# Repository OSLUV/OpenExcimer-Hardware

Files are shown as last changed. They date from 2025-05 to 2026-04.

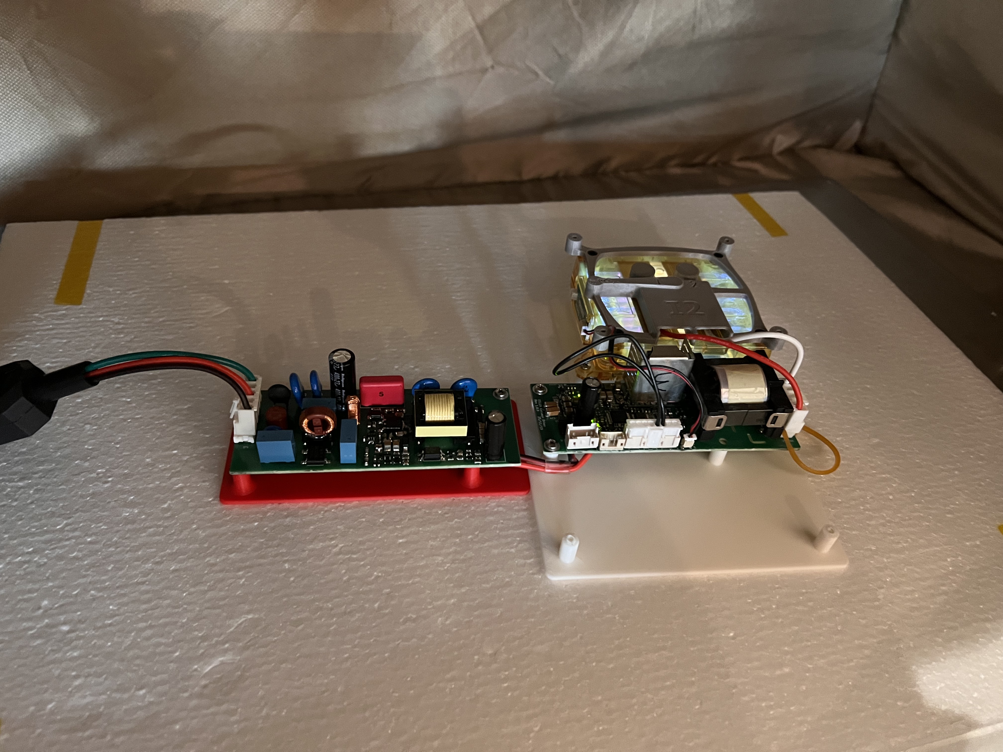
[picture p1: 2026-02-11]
Rev 1.0.0 - Open Excimer EMI Precompliance Data - 10FEB2026/OpenExcimer - Linear Arrangement - Test Set Up.jpeg

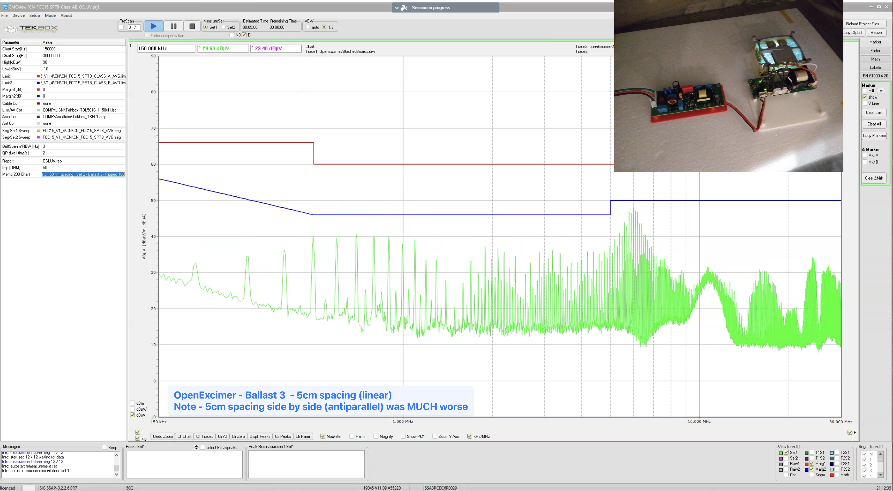
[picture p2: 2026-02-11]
Rev 1.0.0 - Open Excimer EMI Precompliance Data - 10FEB2026/Other Tests/OpenExcimer - 5cm spacing - Linear Arrangement - Passes Class B.png

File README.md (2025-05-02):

# OpenExcimer-Hardware
Hardware for OSLUV open source high voltage excimer lamp driver/ballast intended for 222nm KrCl excimer lamps

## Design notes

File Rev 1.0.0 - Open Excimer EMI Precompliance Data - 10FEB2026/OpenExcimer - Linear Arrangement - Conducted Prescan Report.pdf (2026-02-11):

## EMCview Pre-Compliance Measurement Report 2/10/2026 5:30:08 PM

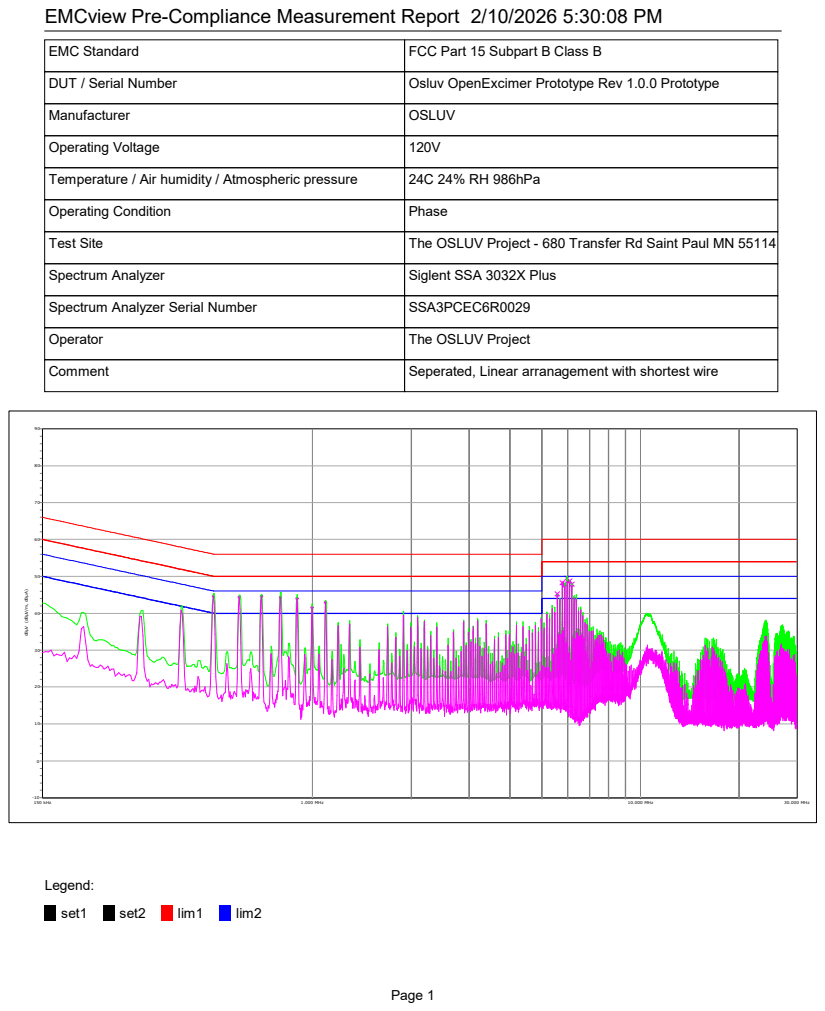
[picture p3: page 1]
EMC Standard; FCC Part 15 Subpart B Class B; DUT / Serial Number; Osluv OpenExcimer Prototype Rev 1.0.0 Prototype; Manufacturer; OSLUV; Operating Voltage; Temperature / Air humidity / Atmospheric pressure; 24C 24% RH 986hPa; Operating Condition; Phase; Test Site; The OSLUV Project - 680 Transfer Rd Saint Paul MN 55114; Spectrum Analyzer; Siglent SSA 3032X Plus; Spectrum Analyzer Serial Number; SSA3PCEC6R0029; Operator; The OSLUV Project; Comment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

EmcView: V11.09 #55220
Project:
Project: [CN_FCC15_SPTB_Class_AB_OSLUV.prj]

Set1:
SEG: FCC15_V1_4\CN\CN_FCC15_SPTB_QP.seg
SEG: FCC15_V1_4\CN\CN_FCC15_SPTB_AVG.seg_rtr10 LIM: FCC15_V1_4\CN\CN_FCC15_SPTB_CLASS_B_QP.lim

Set2:
SEG: FCC15_V1_4\CN\CN_FCC15_SPTB_AVG.seg
SEG: FCC15_V1_4\CN\CN_FCC15_SPTB_PK.seg_rtr10 LIM: FCC15_V1_4\CN\CN_FCC15_SPTB_CLASS_B_AVG.lim

HW Setup:
LISN: COMP\LISN\Tekbox_TBL5016_1_50uH.lsc CABLE:none
ANT:none
AMP:COMP\Amplifiers\Tekbox_TBFL1.amp ANT1:none

Page 2

Peaks Set1

Nb | Det | Freq | Level | Lim | Margin | *DET | *Freq | *Level | *Lim | *Margin | Result
| | [kHz] | dBµV | dBµV | [dB] | | [kHz] | dBµV | dBµV | [dB]

Peaks Set2

Nb | Det | Freq | Level | Lim | Margin | *DET | *Freq | *Level | *Lim | *Margin | Result
| | [kHz] | dBµV | dBµV | [dB] | | [kHz] | dBµV | dBµV | [dB]
1 | VAV | 49 7.8 | 44.56 | 46.03 | 1.47 | | | | | | passed
2 | VAV | 598.07 | 44.39 | 46.00 | 1.61 | | | | | | passed
3 | VAV | 698.33 | 44.58 | 46.00 | 1.42 | | | | | | passed
4 | VAV | 79 8.6 | 44.34 | 46.00 | 1.66 | | | | | | passed
5 | VAV | 895.73 | 44.03 | 46.00 | 1.97 | | | | | | passed
6 | VAV | 996 | 41.61 | 46.00 | 4.39 | | | | | | passed
7 | VAV | 1 096.27 | 42.97 | 46.00 | 3.03 | | | | | | passed
8 | VAV | 5 580 | 44.83 | 50.00 | 5.17 | QP | 5 580 | 45.24 | 60.00 | 14.76 | passed
9 | VAV | 5 780 | 48.01 | 50.00 | 1.99 | QP | 5 780 | 48.25 | 60.00 | 11.75 | passed
10 | VAV | 5 880 | 47.34 | 50.00 | 2.66 | QP | 5 880 | 47.95 | 60.00 | 12.05 | passed
11 | VAV | 5 980 | 48.64 | 50.00 | 1.36 | QP | 597 5.5 | 49.52 | 60.00 | 10.48 | passed
12 | VAV | 6 080 | 48.42 | 50.00 | 1.58 | QP | 607 5.5 | 48.74 | 60.00 | 11.26 | passed
13 | VAV | 6 176.67 | 47.45 | 50.00 | 2.55 | QP | 6 176.67 | 47.91 | 60.00 | 12.09 | passed
14 | VAV | 6 276.67 | 44.05 | 50.00 | 5.95 | | | | | | passed

Page 3

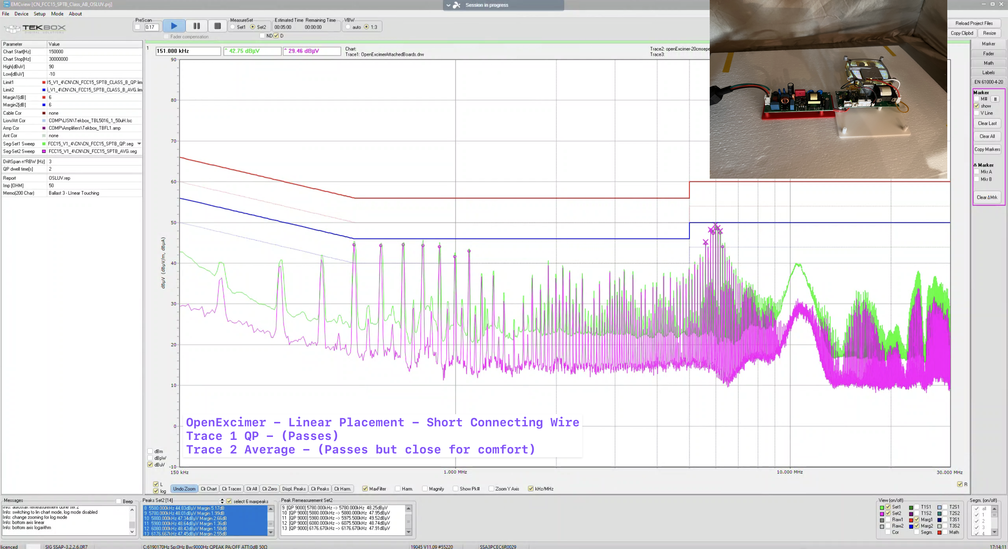
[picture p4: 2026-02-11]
Rev 1.0.0 - Open Excimer EMI Precompliance Data - 10FEB2026/OpenExcimer - Linear Arrangement - Conducted Prescan Overview.png

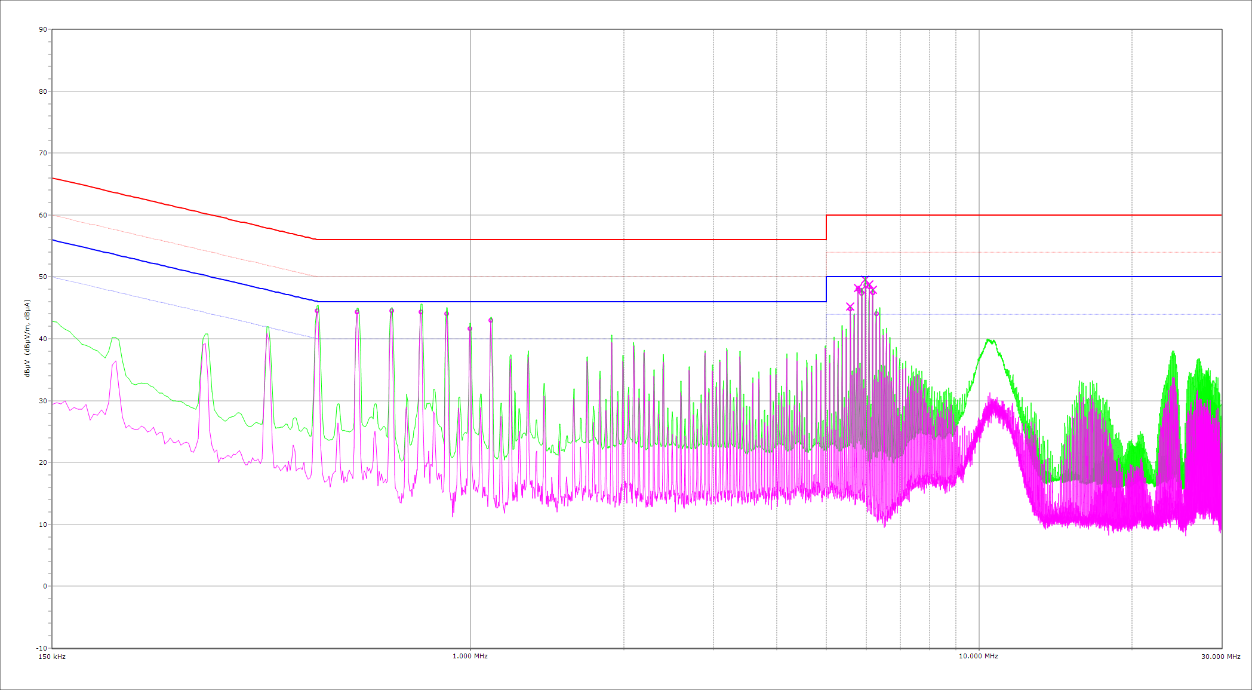
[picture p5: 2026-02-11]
Rev 1.0.0 - Open Excimer EMI Precompliance Data - 10FEB2026/OpenExcimer - Linear Arrangement - Conducted Prescan.png

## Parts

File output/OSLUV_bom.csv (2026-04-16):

Designator | Comment | Footprint | Manufacturer_Part_Number | JLCPCB Part #
L2 | 10uH | Inductor_SMD:L_0805_2012Metric | MLZ2012N100LT000 | C88182
F1 | 1A | Fuse:Fuse_1206_3216Metric | 0440001.WR | C2934573
R35 | 0R02 1% 1206 | Resistor_SMD:R_1206_3216Metric | PA1206FRF470R02L | C728292
R65,R66 | 0R22 1206 | Resistor_SMD:R_1206_3216Metric | RL1206FR-070R22L | C155692
R57 | 100k 0603 | Resistor_SMD:R_0603_1608Metric | RC0603FR-07100KL | C14675
C3,C4,C25,C27,C28,C29,C32,C33,C34,C35,C41,C44,C46,C54 | 100n 0603 | Capacitor_SMD:C_0603_1608Metric | CL10B104KC8NNNC | C15725
C40,C48,C57 | 100p 0603 | Capacitor_SMD:C_0603_1608Metric | CL10C101JC8NNNC | C296717
R29,R44,R45,R54 | 100R 0603 | Resistor_SMD:R_0603_1608Metric | RC0603FR-07100RL | C105588
R33,R34,R37,R46,R47,R52,R55,R58,R73,R74,R75,R79,R82 | 10k 0603 | Resistor_SMD:R_0603_1608Metric | RC0603FR-0710KL | C98220
R48,R78 | 10Meg 0603 | Resistor_SMD:R_0603_1608Metric | RC0603FR-0710ML | C114606
C38 | 10n 0603 | Capacitor_SMD:C_0603_1608Metric | CL10B103KC8NNNC | C84709
C49,C50 | 10p 1% 600V 1206 | Capacitor_SMD:C_1206_3216Metric | CC1206JKNPOCBN100 | C107172
R28,R30 | 10R 0603 | Resistor_SMD:R_0603_1608Metric | RC0603FR-0710RL | C109318
C5,C16,C17,C30,C31,C36,C37,C39,C43,C45,C47,C56 | 10µ X7R 1210 | Capacitor_SMD:C_1210_3225Metric | CL32B106KBJNNNE | C138687
R69 | 12k 0.1% 0603 | Resistor_SMD:R_0603_1608Metric | RT0603BRD0712KL | C326735
R60,R63 | 150R 0805 | Resistor_SMD:R_0805_2012Metric | RC0805FR-07150RL | C114523
R70,R71 | 180R 1206/MMA | Resistor_SMD:R_1206_3216Metric | MMA02040C1800FB300 | C2928662
L1,L5 | 1812_744045008 | Inductor_SMD_Wurth:L_Wurth_WE-LQ-1812 | 744045008
R64 | 18k 0603 | Resistor_SMD:R_0603_1608Metric | RC0603FR-0718KL | C114610
IC8 | 1ED44175N01BXTSA1 | Package_TO_SOT_SMD:SOT-23-6 | 1ED44175N01B | C530933
R27,R36,R38,R39,R61,R62,R77 | 1k 0603 | Resistor_SMD:R_0603_1608Metric | RC0603FR-071KL | C22548
R31,R32,R51 | 1k5 0603 | Resistor_SMD:R_0603_1608Metric | RC0603FR-071K5L | C114668
R67,R68 | 1M 1% 500V 1206 | Resistor_SMD:R_1206_3216Metric | KTR18EZPF1004 | C253347
C26,C53 | 1n 0603 | Capacitor_SMD:C_0603_1608Metric | CL10B102KC8NNNC | C153291
C51 | 1n 1% C0G 0603 | Capacitor_SMD:C_0603_1608Metric | CC0603FRNPO0BN102 | C576765
C55 | 1u 0603 | Capacitor_SMD:C_0603_1608Metric | CL10B105KB8NQNC | C5199872
C1 | 1u X7R 0805 | Capacitor_SMD:C_0805_2012Metric | CL21B105KBFNNNE | C28323
R49 | 220k 0603 | Resistor_SMD:R_0603_1608Metric | RC0603FR-07220KL | C123420
C6,C24 | 2211_8853522130151 | Capacitor_SMD_Wurth:C_Wurth_WCAP-CSSA-2211 | SCC2211X222K502TS | C2915770
R80 | 22k 0603 | Resistor_SMD:R_0603_1608Metric | RC0603FR-0722KL | C114065
R40,R41,R53 | 2k2 0603 | Resistor_SMD:R_0603_1608Metric | AC0603FR-072K2L | C125931
C101 | 330µ 35V | Capacitor_THT:CP_Radial_D8.0mm_P3.50mm | 35ZLJ330M8X20 | C88770
R76 | 33R 0603 | Resistor_SMD:R_0603_1608Metric | RC0603FR-0733RL | C108661
R50 | 39k 0603 | Resistor_SMD:R_0603_1608Metric | RC0603FR-0739KL | C163424
R56,R72 | 3k3 0603 | Resistor_SMD:R_0603_1608Metric | RC0603FR-073K3L | C108078
D10 | 3KASMC24AHE3 | Diode_SMD:D_SMC | 3KASMC24A | C1983631
L3,L4 | 4030_74438357068 | Inductor_SMD_Wurth:L_Wurth_WE-MAPI-4030 | 74438357068
C52 | 47n 0603 | Capacitor_SMD:C_0603_1608Metric | CL10B473KC8WPNC | C307354
R59 | 5k6 0603 | Resistor_SMD:R_0603_1608Metric | RC0603FR-075K6L | C114627
R42,R43 | 680R 0805 | Resistor_SMD:R_0805_2012Metric | RC0805FR-07680RL | C114549
IC5,IC6 | AP63300WU-7 | SOT95P280X90-6N | AP63300WU-7 | C2158012
J5 | B4B-PH-K-S_LF__SN_ | Hansmann_Kontakte:B4B-PH-K-S | B4B-PH-K-S(LF)(SN) | C131334
J1 | B04B-XASK-1_LF__SN_ | B04BXASK1LFSN | B04B-XASK-1(LF)(SN) | C264994
J2 | B08B-XASK-1-A_LF__SN_ | Connector_JST:JST_XA_B08B-XASK-1-A_1x08_P2.50mm_Vertical | B08B-XASK-1-A(LF)(SN) | C491710
J6 | B2P5-VH | Hansmann:CONN_B2P5-VH_JST | B2P5-VH | C594162
D16,D17,D18,D19,D20,D21 | BAT54J | Diode_SMD:D_SOD-323F | BAT54JFILM | C86299
T3 | BC817-40 | Package_TO_SOT_SMD:SOT-23 | BC817-40,215 | C52801
J4 | BM02B-SRSS-TB_LF__SN_ | Hansmann:BM02BSRSSTBLFSN | BM02B-SRSS-TB(LF)(SN) | C160388
D13,D14 | D5V0P4UR6SO-7 | SOT95P285X140-6N | D5V0P4UR6SO-7 | C531179
T2,T4,T5 | DCX114EU-7-F | SOT65P210X110-6N | DCX114EU-7-F | C460018
L101 | ETD29 | B66359B1013T001 | B66359B1013T001
T101 | IMZC120R078M2H | Package_TO_SOT_THT:TO-247-4_Vertical | IMZC120R078M2HXKSA1 | C44184296
IC4 | INA210 | Package_TO_SOT_SMD:SOT-363_SC-70-6 | INA210AIDCKR | C353893
M1 | K 274 MI 247 V | Hansmann_Kühlkörper:FK 274 MI 247 V | FK 274 MI 247 V
D12,D15 | LED gr 0603 | LED_SMD:LED_0603_1608Metric | XL-1608UGC-04 | C965804
D11 | LED rd 0603 | LED_SMD:LED_0603_1608Metric | XL-1608SURC-06 | C965799
IC2 | LM2901 | Package_SO:TSSOP-14_4.4x5mm_P0.65mm | LM2901PWR | C54868
IC7 | LP2985-33DBVR | SOT95P280X145-5N | LP2985-33DBVR | C95414
IC1 | OPA2356AIDGKR | Package_SO:VSSOP-8_3.0x3.0mm_P0.65mm | OPA2356AIDGKR | C2057371
F2 | Polyfuse 200 mA | Fuse:Fuse_1206_3216Metric | MF-NSMF020-2 | C185112
TH1 | PTC 680R 80°C | Resistor_SMD:R_0805_2012Metric | B59721A0080A062 | C2655235
M2 | Silicone gap pad, 200µm, Ubd≥5kV, λ≥1.9 W/mK. 24 x 22 mm. Acc. to drawing from 08.01.2026 | Hansmann_Kühlkörper:GapPad_19mm | KU-CG20
IC3 | STM32G071KBT6 | Hansmann:QFP80P900X900X160-32N | STM32G071KBT6 | C529348
VR1 | TC33X-2-103E | TC33X2503E | TC33X-2-103E | C719176

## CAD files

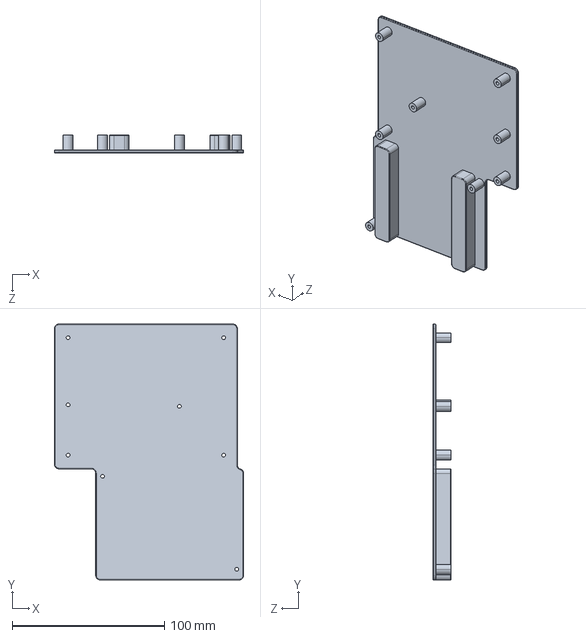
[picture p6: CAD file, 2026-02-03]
test_fixture/test_fixture.step
124.1 x 167.9 x 12.0 mm

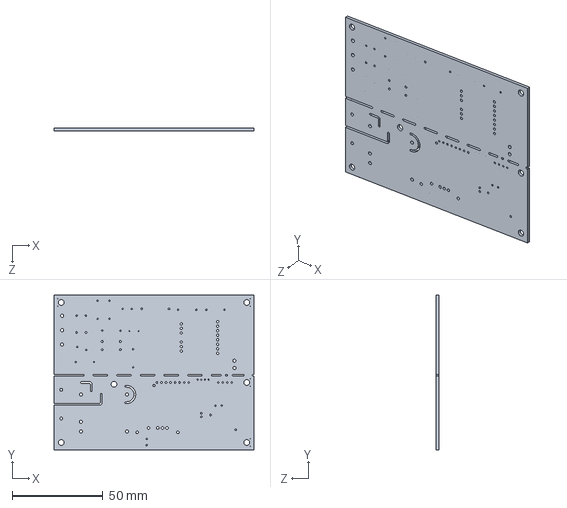
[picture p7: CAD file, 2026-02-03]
test_fixture/osluv_pcb.sldprt
110.0 x 85.0 x 1.51 mm

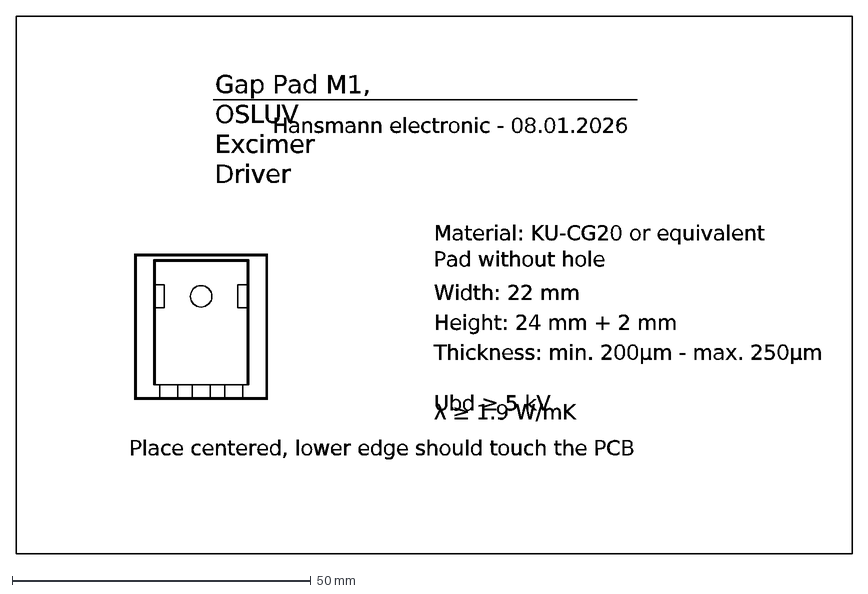
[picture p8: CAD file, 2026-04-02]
Gappad/260108_GapPad_M1.dxf
Material: KU-CG20 or equivalent
Pad without hole
Width: 22 mm
Height: 24 mm + 2 mm
Thickness: min. 200µm - max. 250µm
U^bd ≥ 5 kV
λ ≥ 1.9 W/mK
Place centered, lower edge should touch the PCB
Hansmann electronic - 08.01.2026
Gap Pad M1, OSLUV Excimer Driver

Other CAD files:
Transformer/OSLUV_Trafo-Construction_Rev1.dwg
test_fixture/test_fixture.sldprt

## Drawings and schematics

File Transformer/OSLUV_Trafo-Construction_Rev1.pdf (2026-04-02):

## ETD29 L101 OSLUV Driver

## Change Log

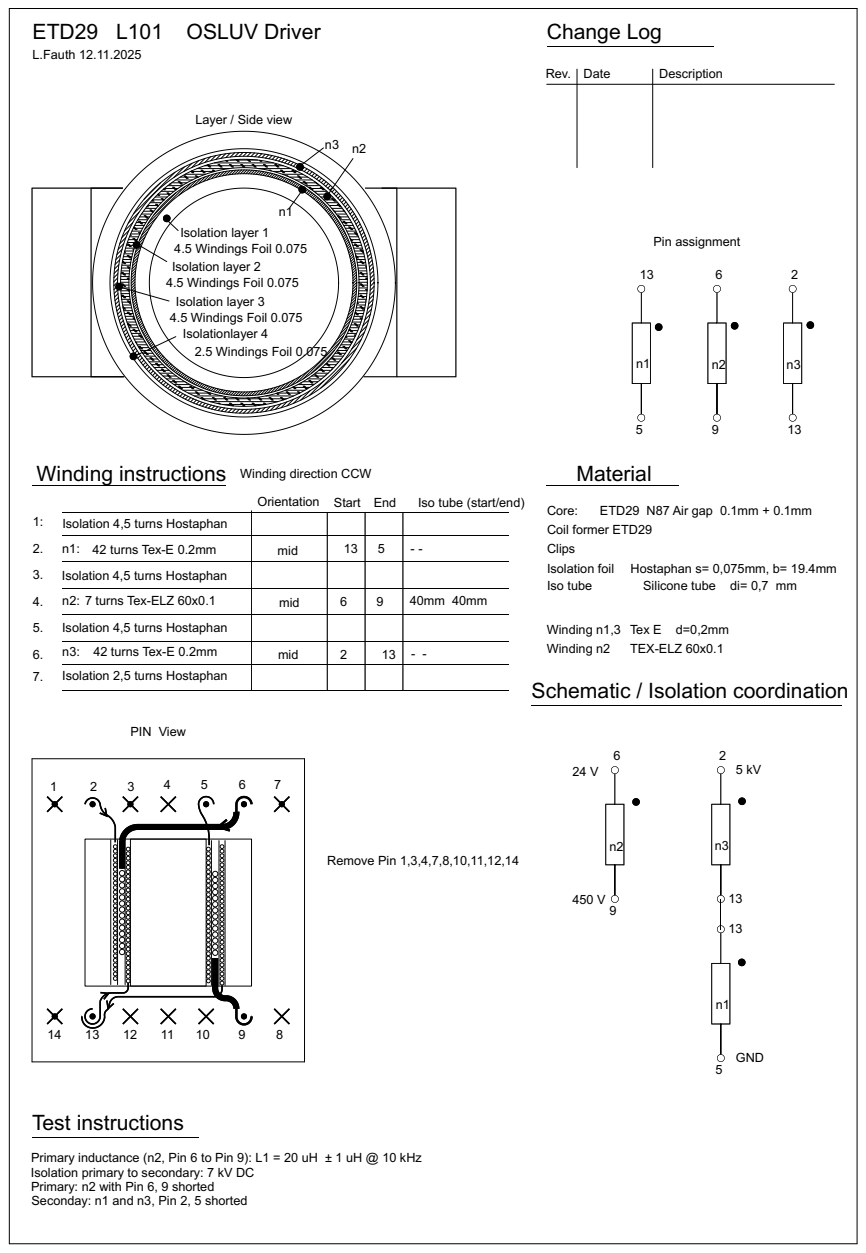
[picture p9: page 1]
Start; Isolation layer 1 4.5 Windings Foil 0.075; Isolation layer 2 4.5 Windings Foil 0.075; Isolation layer 3 4.5 Windings Foil 0.075 Isolationlayer 4 2.5 Windings Foil 0.075; GND; Pin assignment; Winding instructions n1:; End; Iso tube (start/end); Rev.; Date; Description; Isolation 2,5 turns Hostaphan; - - 7 turns Tex-ELZ 60x0.1; Core:; ETD29 N87 Air gap 0.1mm + 0.1mm; Material; Test instructions; Hostaphan s= 0,075mm, b= 19.4mm; Silicone tube; Winding n1,3 Tex E; L.Fauth 12.11.2025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

Layer / Side view

Isolation 4,5 turns Hostaphan

Winding direction CCW
Orientation mid mid mid

Coil former ETD29
Clips
Isolation foil
Iso tube Winding n2

Schematic / Isolation coordination

Primary inductance (n2, Pin 6 to Pin 9): L1 = 20 uH ± 1 uH @ 10 kHz
Isolation primary to secondary: 7 kV DC
Primary: n2 with Pin 6, 9 shorted
Seconday: n1 and n3, Pin 2, 5 shorted

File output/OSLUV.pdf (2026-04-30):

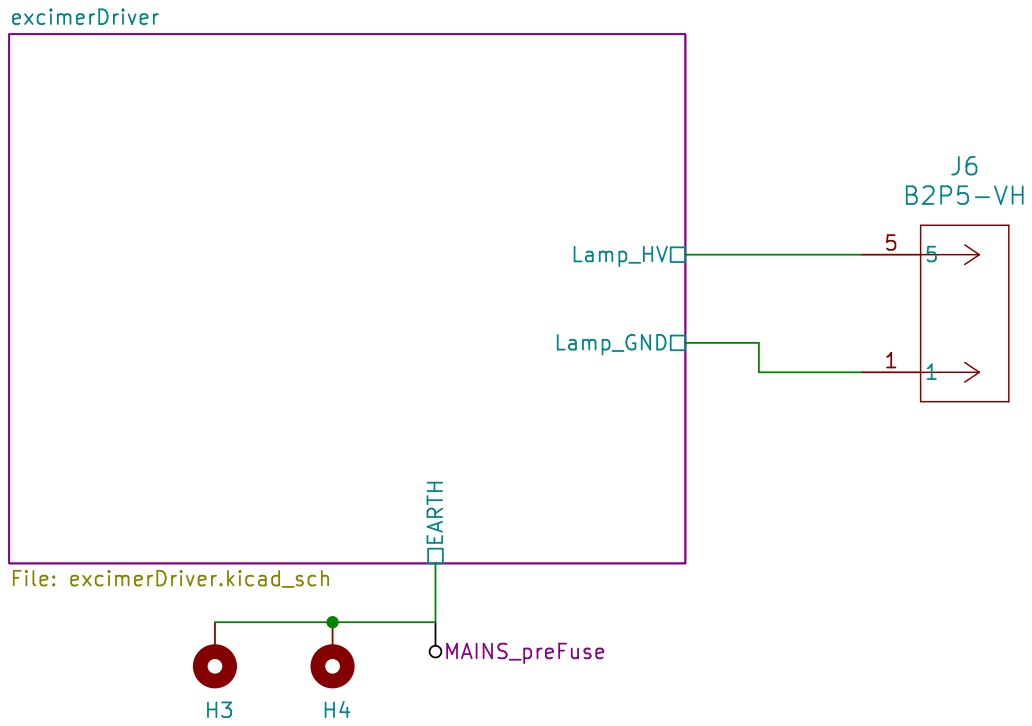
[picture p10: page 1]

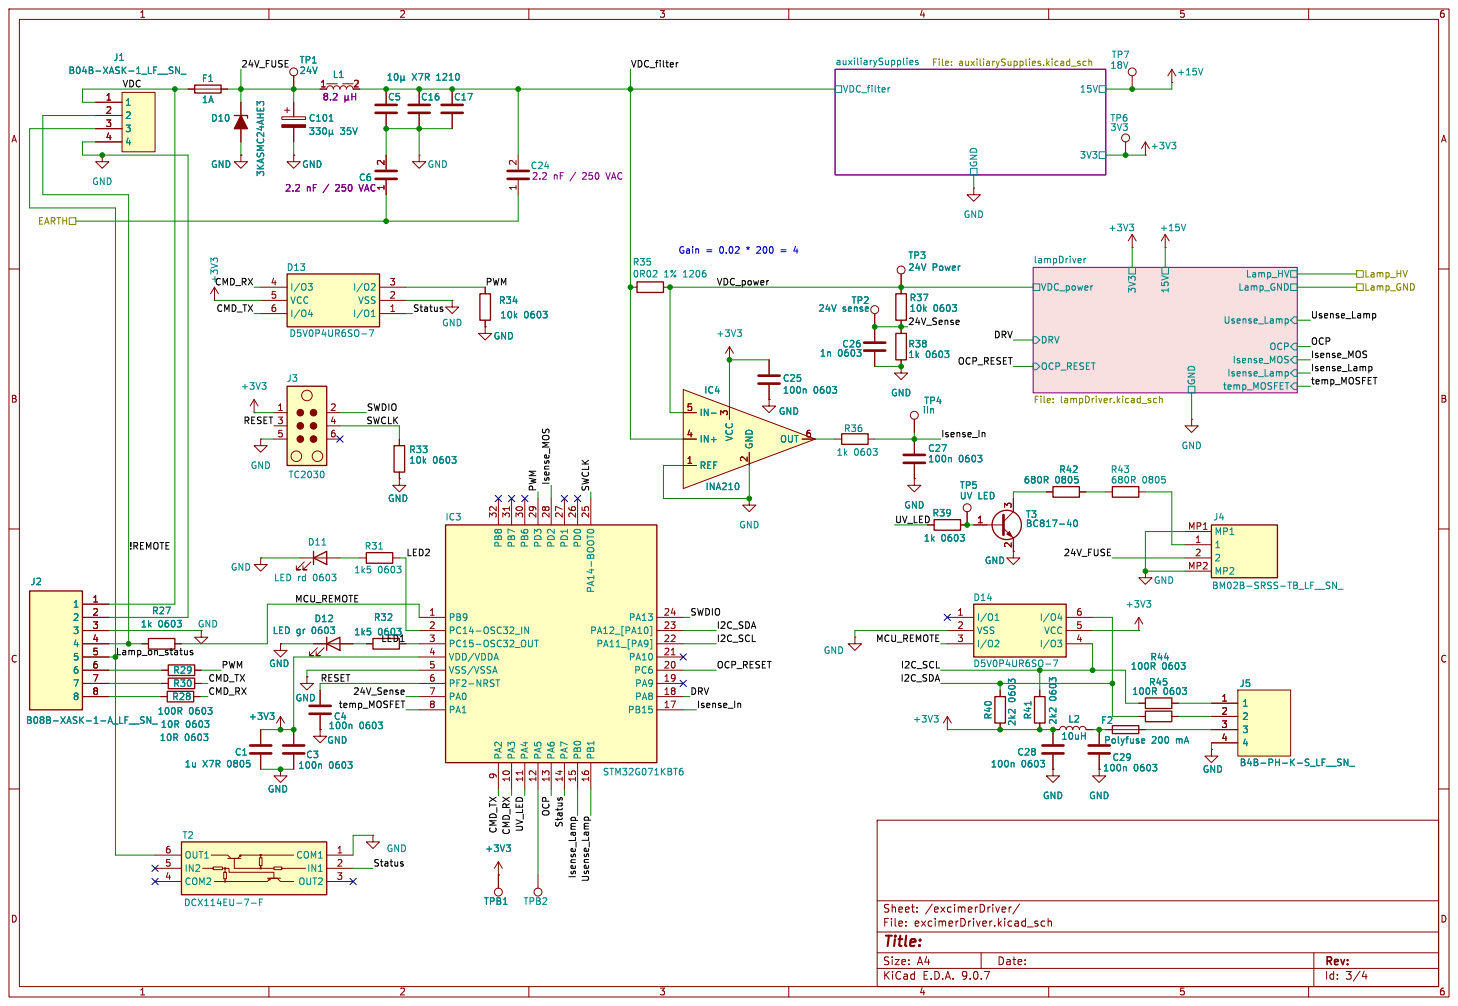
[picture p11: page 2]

Id: 3/4 Title: File: excimerDriver.kicad_sch Sheet: /excimerDriver/

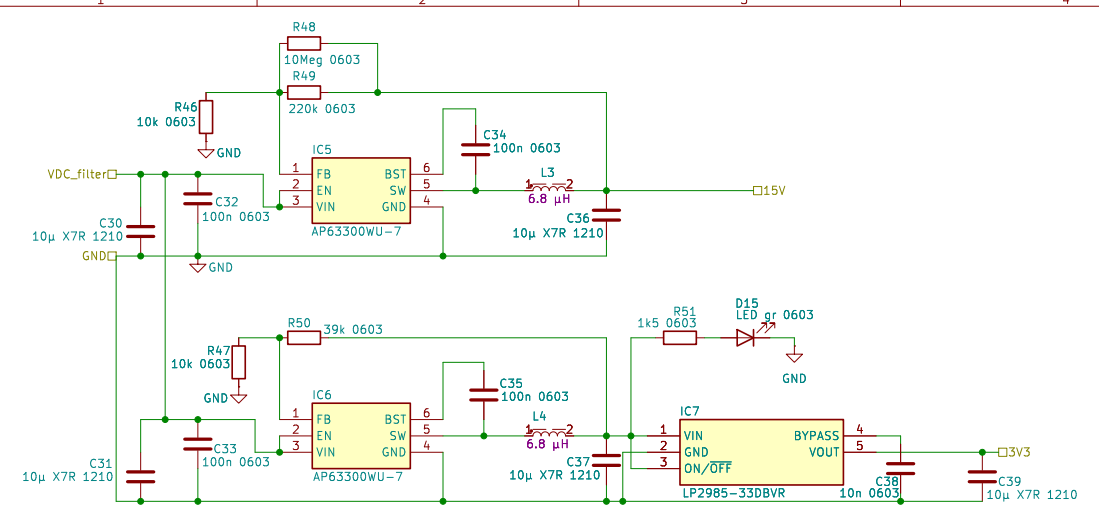
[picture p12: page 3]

Id: 4/4 Title: File: auxiliarySupplies.kicad_sch Sheet: /excimerDriver/auxiliarySupplies/

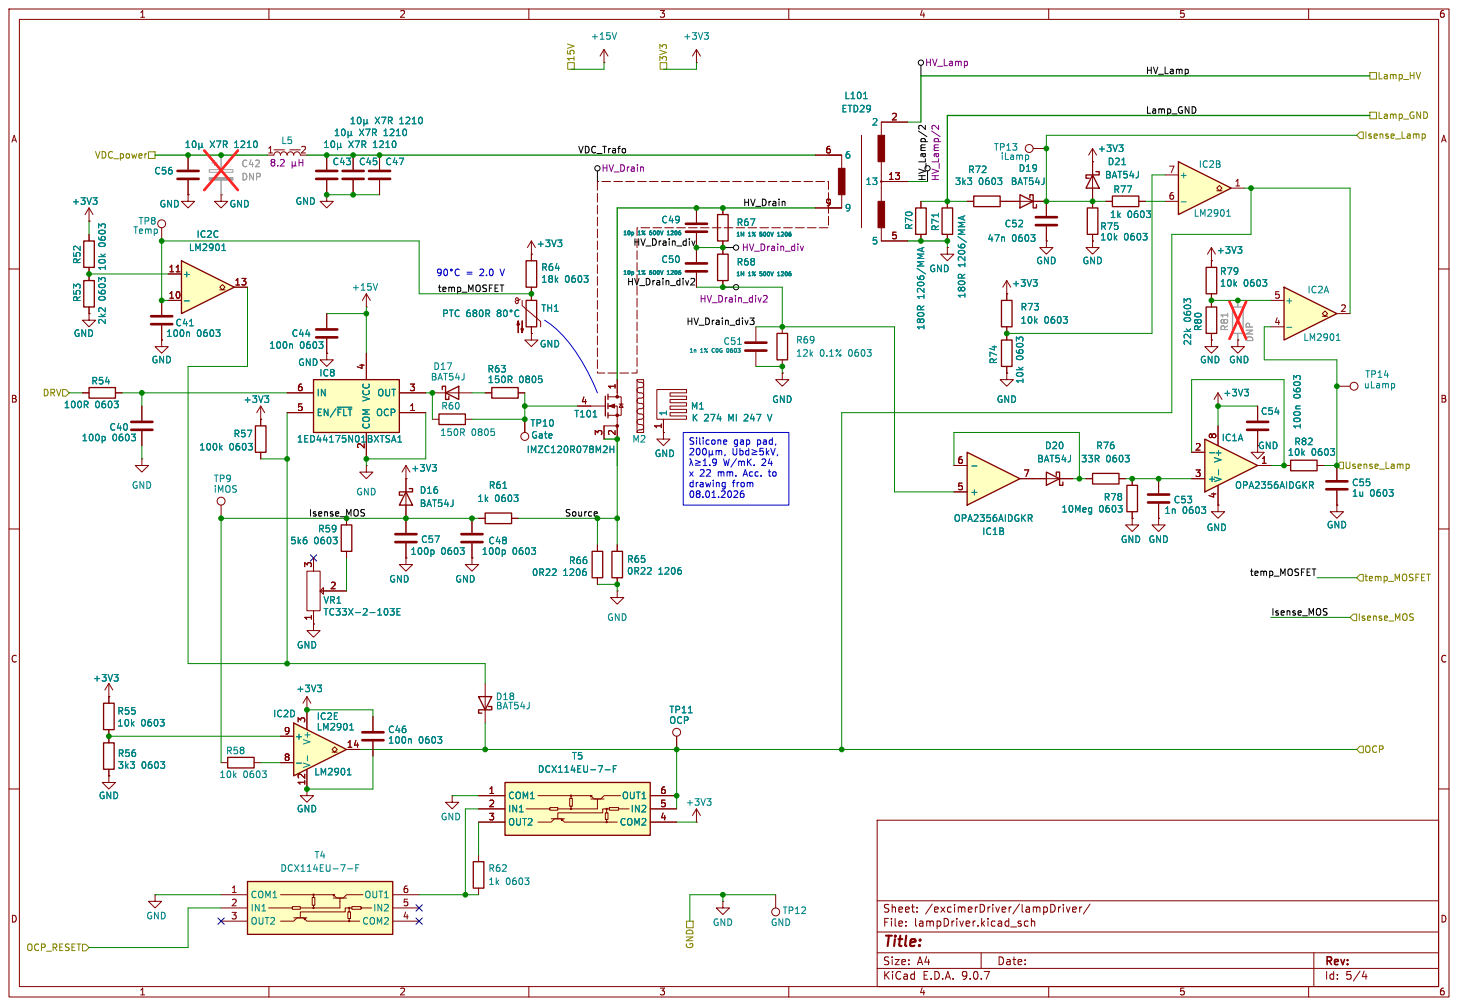
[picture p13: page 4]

Id: 5/4 Title: File: lampDriver.kicad_sch Sheet: /excimerDriver/lampDriver/

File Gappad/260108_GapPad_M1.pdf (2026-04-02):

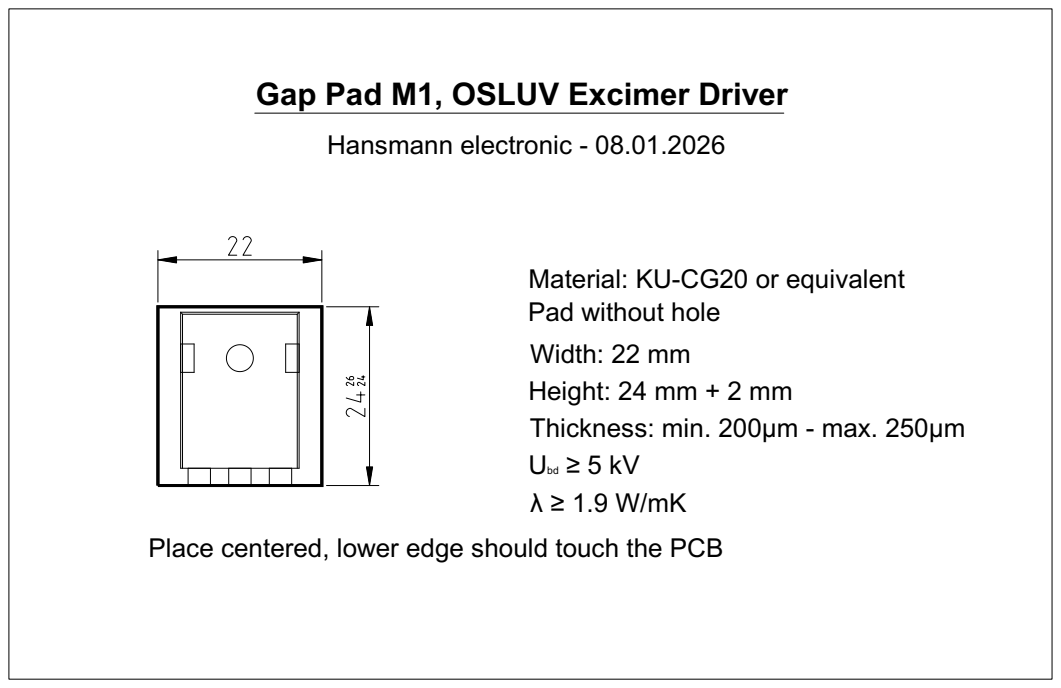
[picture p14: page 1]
Hansmann electronic - 08.01.2026

Gap Pad M1, OSLUV Excimer Driver

Material: KU-CG20 or equivalent
Pad without hole
Width: 22 mm
Height: 24 mm + 2 mm
Thickness: min. 200µm - max. 250µm
Ubd ≥ 5 kV

Place centered, lower edge should touch the PCB

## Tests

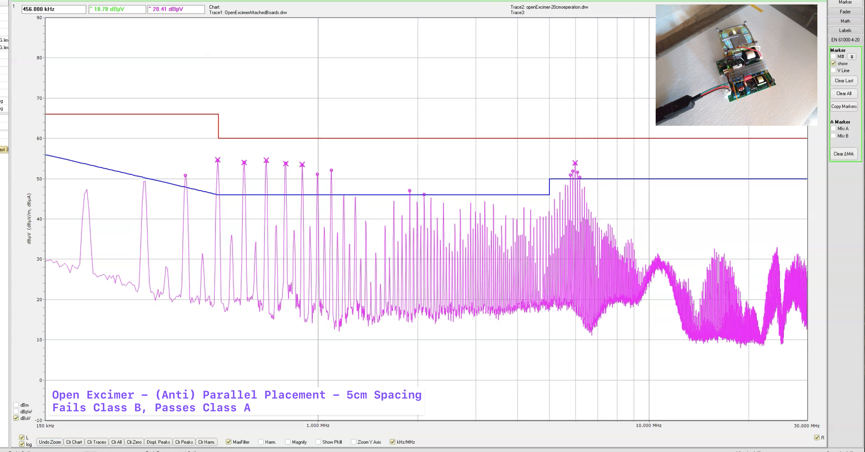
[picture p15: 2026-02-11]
Rev 1.0.0 - Open Excimer EMI Precompliance Data - 10FEB2026/Other Tests/OpenExcimer - 5cm spacing - Antiparallel Arrangement.png

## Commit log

2025-05-06 update of schematic
    [LampIntensity.kicad_sch, OSLUV.kicad_pcb, OSLUV.kicad_sch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]
2025-05-06 schematic done, not placed
    [OSLUV.kicad_pcb, OSLUV.kicad_sch, excimerDriver.kicad_sch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]
2025-05-06 restore to 9.0
    [LampIntensity.kicad_sch, OSLUV.kicad_pcb, OSLUV.kicad_sch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]
2025-05-06 power parts routed
    [OSLUV.kicad_pcb, auxiliarySupplies.kicad_sch, lampDriver.kicad_sch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]
2025-05-06 old current control design
    [OSLUV.kicad_pcb, lampDriver.kicad_sch, offlineConverter.kicad_sch]
2025-05-06 new current control V1
    [OSLUV.kicad_pcb, excimerDriver.kicad_sch, lampDriver.kicad_sch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]
2025-05-06 251704 end of day
    [excimerDriver.kicad_sch, offlineConverter.kicad_sch]
2025-05-06 branch main, transfomer changed to EF25
    [OSLUV.kicad_pcb, OSLUV.kicad_sch, excimerDriver.kicad_sch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]
2025-05-06 new transformer, top layer only
    [OSLUV.kicad_pcb, OSLUV_kopie.kicad_pcb, excimerDriver.kicad_sch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]
2025-05-06 routing single side done
    [LampIntensity.kicad_sch, OSLUV.kicad_pcb, OSLUV.kicad_sch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]
2025-05-06 initial version of excimer driver PCB
    [OSLUV.kicad_pcb, OSLUV_kopie.kicad_pcb, excimerDriver.kicad_sch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]
2025-05-06 error correction
    [OSLUV.kicad_pcb, excimerDriver.kicad_sch]
2025-05-16 alpha prototype
    [OSLUV.kicad_pcb, excimerDriver.kicad_sch, lampDriver.kicad_sch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]
2025-06-03 error correction first prototype
    [OSLUV.kicad_pcb, auxiliarySupplies.kicad_sch, excimerDriver.kicad_sch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]
2025-07-01 etd29 transformer single layer
    [OSLUV.kicad_pcb, excimerDriver.kicad_sch, lampDriver.kicad_sch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]
2025-07-01 added new transformer V2
    [OSLUV.kicad_pcb, excimerDriver.kicad_sch, lampDriver.kicad_sch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]
2025-08-11 V2 PCB
    [OSLUV.kicad_pcb, auxiliarySupplies.kicad_sch, excimerDriver.kicad_sch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]
2025-08-25 Beta Prototype production data, KiCad Stable version
    [LampIntensity.kicad_sch, OSLUV.kicad_pcb, OSLUV.kicad_sch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]
2025-10-20 Made 3D model of prototype ballast.
    [osluv_ballast_prototype.sldprt]
2026-02-03 Made test fixture.
    [osluv_pcb.sldprt, test_fixture.sldprt, test_fixture.step]
2026-02-11 added emi conducted mode precompliance data for rev 1.0.0
    [OpenExcimer - Linear Arrangement - Conducted Prescan.csv]
2026-03-03 Final Rev. 1.0.0
    [OSLUV.kicad_pcb, excimerDriver.kicad_sch, lampDriver.kicad_sch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]
2026-03-26 Final Version Rev. 2.0.0
    [OSLUV-B_Cu.gbr, OSLUV-B_Mask.gbr, OSLUV-B_Paste.gbr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]
2026-03-26 Cleanup rep
    [LampIntensity.kicad_sch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]
2026-04-02 added transformer and gap pad drawing
    [260108_GapPad_M1.dxf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]
2026-04-02 internalized library, 3d files
    [OSLUV.kicad_pcb, excimerDriver.kicad_sch, lampDriver.kicad_sch]
2026-04-02 export footprints as STEP
    [643495-2.stp, B04B-XASK-1.step, B08B-XASK-1.step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]
2026-04-02 export footprints as STEP, fixed
    [OSLUV.kicad_pcb]
2026-04-07 3d models
    [OSLUV.kicad_pcb]
2026-04-16 Fixed BoM, and added jobset.
    [OSLUV-B_Cu.gbl, OSLUV-B_Mask.gbs, OSLUV-B_Paste.gbp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]
2026-04-16 Removing old manufacturing files.
    [OSLUV-B_Cu.gbl, OSLUV-B_Cu.gbr, OSLUV-B_Mask.gbr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]
2026-04-17 Fixed debug header footprint, and cleaned up silkscreen.
    [OSLUV.kicad_pcb, excimerDriver.kicad_sch, lampDriver.kicad_sch]
2026-04-29 Fixed transformer footprint, and cleaned up silkscreen.
    [OSLUV-B_Cu.gbl, OSLUV-B_Mask.gbs, OSLUV-B_Paste.gbp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]
2026-04-30 Fixed jobset bug, and re-exported.
    [OSLUV-B_Cu.gbl, OSLUV-B_Mask.gbs, OSLUV-B_Paste.gbp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]
